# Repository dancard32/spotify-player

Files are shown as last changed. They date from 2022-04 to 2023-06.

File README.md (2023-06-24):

# Raspberry Pi - RFID Spotify Jukebox

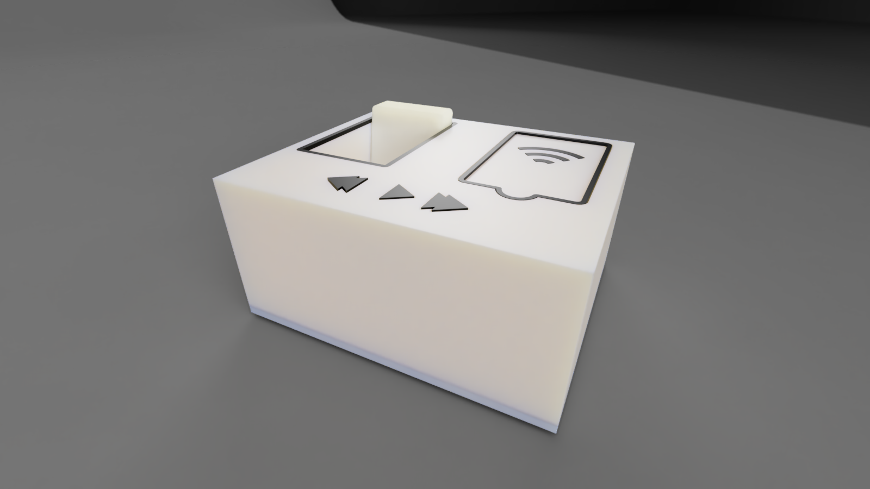
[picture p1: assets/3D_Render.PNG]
Cover Photo

## Description
Ths project employs the [spotipy](https://spotipy.readthedocs.io/en/2.19.0/) Python library to interface with the Spotify web application to create a functional RFID Spotify Jukebox. This Github repository will contain the steps towards creating a functional spotify application as well as containing links to the thingiverse repository of the *.stl* files that I 3D printed as well as the Bill of Materials (BOM).

---
## Table of Contents
- [Bill of Materials](#bill-of-materials)
    - [Raspberry Pi](#raspberry-pi)
    - [RFID Card Reader](#rfid-card-reader)
    - [Miscellaneous Parts](#miscellaneous-parts)
- [Installation and Setup](#installation-and-setup)
    - [Initial Set-up](#initial-set-up)
    - [RC522 Card Reading](#rc522-card-reading)
    - [Connecting Raspberry Pi to Spotify](#connecting-raspberry-pi-to-spotify)
    - [Setting up Developer Spotify API](#setting-up-developer-spotify-api)
    - [Installing Spotipy](#installing-spotipy)
    - [Adding Playlists/Songs to RFID Cards](#adding-playlistssongs-to-rfid-cards)
    - [Enabling Spotipy Script on Boot](#enabling-spotipy-script-on-boot)
- [Printing Album Art](#printing-album-art)
- [3D Printing Jukebox](#3d-printing-jukebox)
- [Credits](#credits)
- [License](#license)

---
## Bill of Materials
Listed below are the bare minimum parts required for a functioning Raspberry Pi RFID Spotify jukebox, with associated links:
- ### Raspberry Pi
    There are several Raspberry Pi's that can be used, but ultimately depend on the implementation
    - [Raspberry Pi 4 Model B](https://www.raspberrypi.com/products/raspberry-pi-4-model-b/)
    - [Raspberry Pi 3 Model B+](https://www.raspberrypi.com/products/raspberry-pi-3-model-b-plus/)
    - [Raspberry Pi 3 Model B](https://www.raspberrypi.com/products/raspberry-pi-3-model-b/)

- ### RFID Card Reader
    It is best to use a [RC522 RFID](https://medium.com/autonomous-robotics/an-introduction-to-rfid-dc6228767691) due to its supported Python library module. You can pick one up [here](https://www.amazon.com/dp/B07VLDSYRW?psc=1&ref=ppx_yo2ov_dt_b_product_details).

- ### Miscellaneous Parts
    - **Speaker**: in this build I used a [JBL Flip 3](https://www.amazon.com/JBL-FLIP3-Bluetooth-Speaker-Black/dp/B010RWAIAC) that I purchased on a Black Friday Deal for $30, any speaker will suffice - edits to the 3D prints will be needed with a different speaker configuration
    - **Button**: to skip tracks, play/pause tracks I used [Tactile Push Button Switch](https://www.amazon.com/QTEATAK-Momentary-Tactile-Button-Switch/dp/B07VSNN9S2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) or a suitable alternative
    - **Audio Jack Splitter**: To allow external speaker player I got this audio jack that will mount into the 3D printed frame [Audio Jack Splitter](https://www.amazon.com/Kingtop-Adapter-Tablet-Headsets-Version/dp/B01I3A47I4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)
    - **RFID Tags**: Link [here](https://www.amazon.com/dp/B01LZYOR7P?psc=1&ref=ppx_yo2ov_dt_b_product_details)
    - **Blank Cards**: Link [here](https://www.amazon.com/dp/B07193KG7G?ref=ppx_yo2ov_dt_b_product_details&th=1)
    - **Threaded inserts**: Link [here](https://www.amazon.com/dp/B08Z86Z85R?psc=1&ref=ppx_yo2ov_dt_b_product_details)
    - **Dupont Connectors**: Link [here](https://www.amazon.com/dp/B089FZ79CS?psc=1&ref=ppx_yo2ov_dt_b_product_details)
    - **Protoboard**: Link [here](https://www.amazon.com/dp/B07FFDFLZ3?psc=1&ref=ppx_yo2ov_dt_b_product_details)
    - **Rubber Standoffs**: Link [here](https://www.amazon.com/dp/B08C373VBW?psc=1&ref=ppx_yo2ov_dt_b_product_details)
    - **Raspberry Pi PS Cable**: Link [here](https://www.amazon.com/dp/B01N336XEU?psc=1&ref=ppx_yo2ov_dt_b_product_details)

---
## Installation and Setup

### Initial Set-up
After a clean install of Raspberry Pi Dameon Linux
```
sudo apt-get update
sudo apt-get upgrade
```
Next type the following
```
sudo raspi-config
```
Raspi-config will open a window, from here select "Interfacing Options" and select "SPI" and enable "SPI"
```
sudo reboot
```

### RC522 Card Reading
To allow the reading of RFID tags, connect the MFRC522 module to the Raspberry Pi via the following pin out schematic
- **SS pin** connects to **GPIO8 pin**
- **SCK pin** connects to **GPIO11 pin**
- **MOSI pin** connects to **GPIO10 pin**
- **MISO pin** connects to **GPIO9 pin**
- **IRQ pin** does not connect to anything
- **GND pin** connects to **GND pin**
- **RST pin** connects to **GPIO23 pin**
- **VCC pin** connects to **3.3V Power pin**

Refer to the pins and connections below
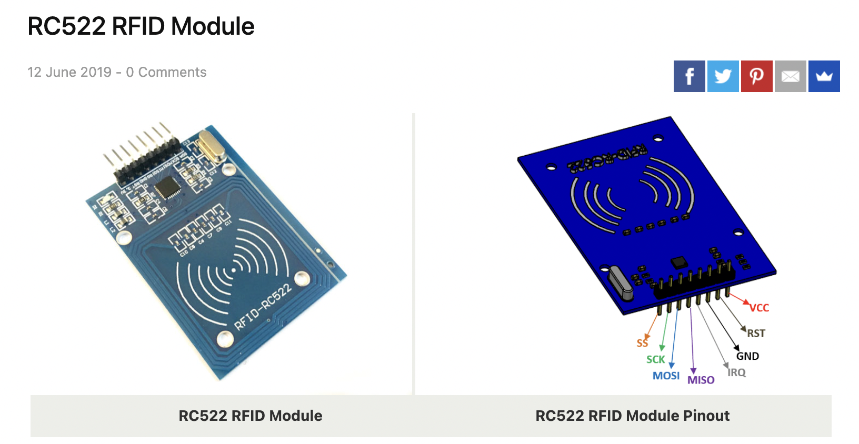
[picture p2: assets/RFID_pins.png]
MFRC522 RFID Card Reader Pin Out

Click here for more [RC522 Data](https://components101.com/wireless/rc522-rfid-module)

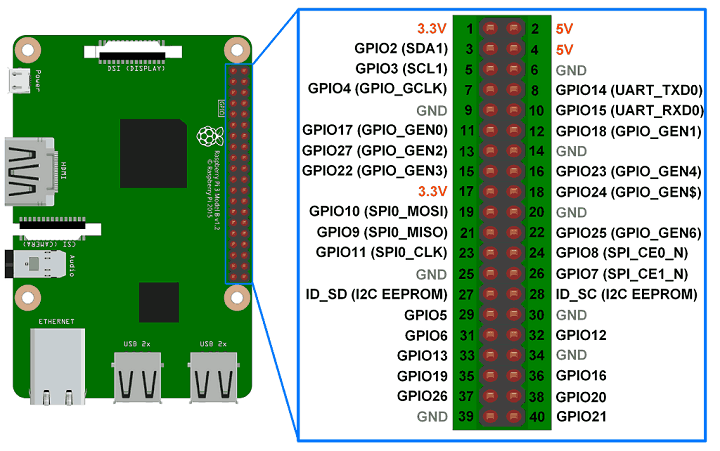
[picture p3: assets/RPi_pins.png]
Raspberry Pi 3/4 GPIO Pin Outs


To allow for the RFID reading, install the following dependencies
```
sudo apt-get install python3-dev python3-pip
sudo pip3 install spidev mfrc522
```
This will enable the Raspberry Pi to access the GPIO pins and read the HASH ID values from the RFID tags that can be used to link to playlists/albums/tracks later on. With these dependencies installed *readCard.py* should be able to run and will output the HASD ID values.

### Connecting Raspberry Pi to Spotify
To enable the Raspberry Pi to be a valid connection on Spotify, the [Raspotify - Spotify Connect](https://github.com/dtcooper/raspotify) client will need to be installed - *be sure that all dependencies are met else connect will not work*- to install use the folllowing command
```
sudo apt-get -y install curl && curl -sL https://dtcooper.github.io/raspotify/install.sh | sh
```
While the Raspberry Pi is on and connected to internet, it should be recognized by Spotify as a valid connection device (analogous to a bluetooth speaker, a separate device, etc). Test functionality by opening Spotify on a phone or laptop and click the **Connect** button and search for "Raspotify" in the options.
### Setting up Developer Spotify API
Next step is too allow the Raspberry Pi to interface with Spotify's web API and allow the Raspberry Pi to change music per the RFID values. To allow *spotipy* to integrate with the Spotify web API, API tokens are required, to obtain them do the following:

1. Navigate to https://developer.spotify.com/dashboard
2. Sign in with a Spotify Premium Account
3. Click "Create an App"
4. Click on your app
5. Click on "Edit Settings"
6. Add the following callback URIs
```
http://localhost:8888/callback
http://localhost:8080 
```
7. On the dashboard, write/copy the Client ID and Client Secret, they are needed later

Next is to get the Device ID of the Raspberry Pi, this can be found after connecting the Raspberry Pi via Spotify Connect

1. On a phone or laptop, open Spotify and connect to "Raspotify"
2. Navigate to https://developer.spotify.com/console/get-users-available-devices/
3. Click get token
4. Check all the boxes under "Required Scopes for this endpoint"
5. Click "Request Token"
6. Underneath the Get token option, click "Try It" to make an API call and get the list of Spotify devices on your home network
7. In the json response, find the ID for the Raspotify (Raspberry Pi) device
8. Write/copy the Device ID

### Installing Spotipy
Spotipy is a lightweight python library for the Spotify web API, click here for [Spotipy Documentation](https://spotipy.readthedocs.io/en/2.19.0/)
```
pip install spotipy
```
Once that installs, we can start writing our first python program to control Spotify on Raspberry Pi.

1. In your main folder, open *parseSpotify.py*
2. Change the Device ID, Client ID, and Client Secret to the tokens provided by Spotify
3. Execute this script
4. A Spotify webpage will open where you have to agree/accept to authenticate. Click agree, this is a one-time setup
5. Once authenticated, the song in *parseSpotify.py* will start playing through the Raspberry Pi speakers

### Adding Playlists/Songs to RFID Cards
With everything up to this point being completed, the Raspberry Pi is ready to play music! Change the token values in *main.py* to match the tokens provided to you from Spotify. From here songs/albums/playlists can be added to the *CardData.json* through the following format shown below:
```
{
    "HASH ID #1 FROM RFID CARD":{
        "name":"Road Trips",
        "url":"spotify:playlist:1LxEqGRyNV5yB67e6mwGgH",
    },
    "HASH ID #2 FROM RFID CARD":{
        "name":"California 37",
        "url":"spotify:album:5zseibu9WEsPaZmkJUMkz1",
    },
    "HASH ID #3 FROM RFID CARD":{
        "name":"Beautiful Mistakes",
        "url":"spotify:track:5zFglKYiknIxks8geR8rcL",
    },
}
```
Where *HASH ID* can be found by running the *readCard.py* script and copying/pasting the RFID HASH ID into *CardData.json* and where *"type"* can be either *Playlist, Album, or Track* as per the Spotify URL. Obtaining the URL can be done simply by:
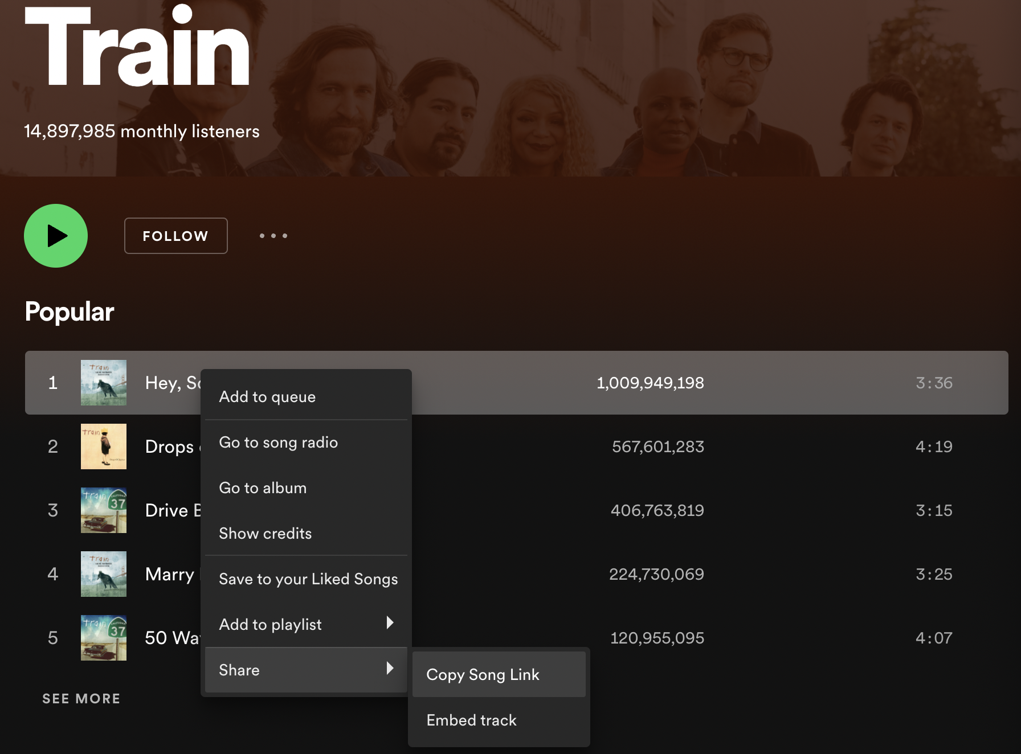
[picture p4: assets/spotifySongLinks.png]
Spotify Song Links


Copying this link gives *https://open.spotify.com/track/4HlFJV71xXKIGcU3kRyttv?si=b945f2f735874dd0* but all that is is needed can be spliced is after the *spotify.com/"type"/* up to the *"?"* such that this track's ID is **4HlFJV71xXKIGcU3kRyttv**. Hence, the value for the card's URL is
```
{
    "name":"Hey, Soul Sister",
    "url":"spotify:track:4HlFJV71xXKIGcU3kRyttv",
    "type": "Track"
}
```
**Note: The type must be correct as album/playlist use a different API call than track, the name can be left blank**

### Enabling Spotipy Script on Boot
Enabling the python script to auto-run on boot can be done by using *crontab* to run a shell script that starts the script on boot. For detailed instructions, refer to [Raspberry Pi Launch Python Script on Startup](https://www.instructables.com/Raspberry-Pi-Launch-Python-script-on-startup/)

---
## Printing Album Art
Included in this repository is the *genPhotos.py* file that will automatically generate the album art to be printed, cut out and pasted onto a blank card to pose as a modern record. All that is required is enabling the *boolean* to automatically pull the album art from Spotify - else you'll have to manually populate the album cover art folder with photos of your choice.

### Custom Art
To print custom artworks (not the album art from Spotify), place your artwork into the *cover_art* folder shown below with the associated name that can be found in the *CardData.json*

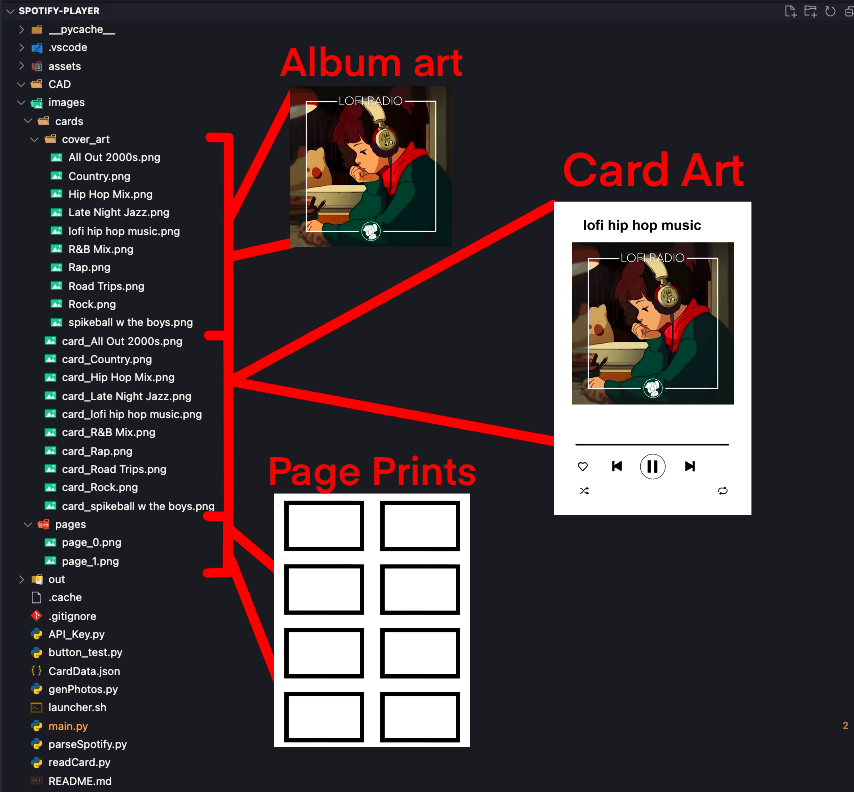
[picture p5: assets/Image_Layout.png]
Image Layout


**Ensure that PullSpotifyData is False if you want custom album art**

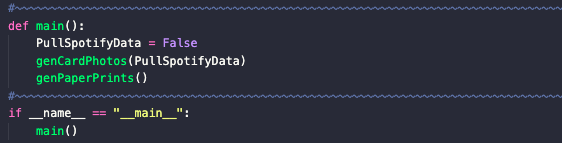
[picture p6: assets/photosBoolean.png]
genPhotos.py Boolean


*genPhotos.py*
## 3D Printing Jukebox
All the 3D printing CAD files can be found under the associated *CAD* folder in this repository. These are in the *.stl* file format to be used during *.gcode* generation. Additionally, the drawing with the bill of materials (BOM) can be found in this folder as well.

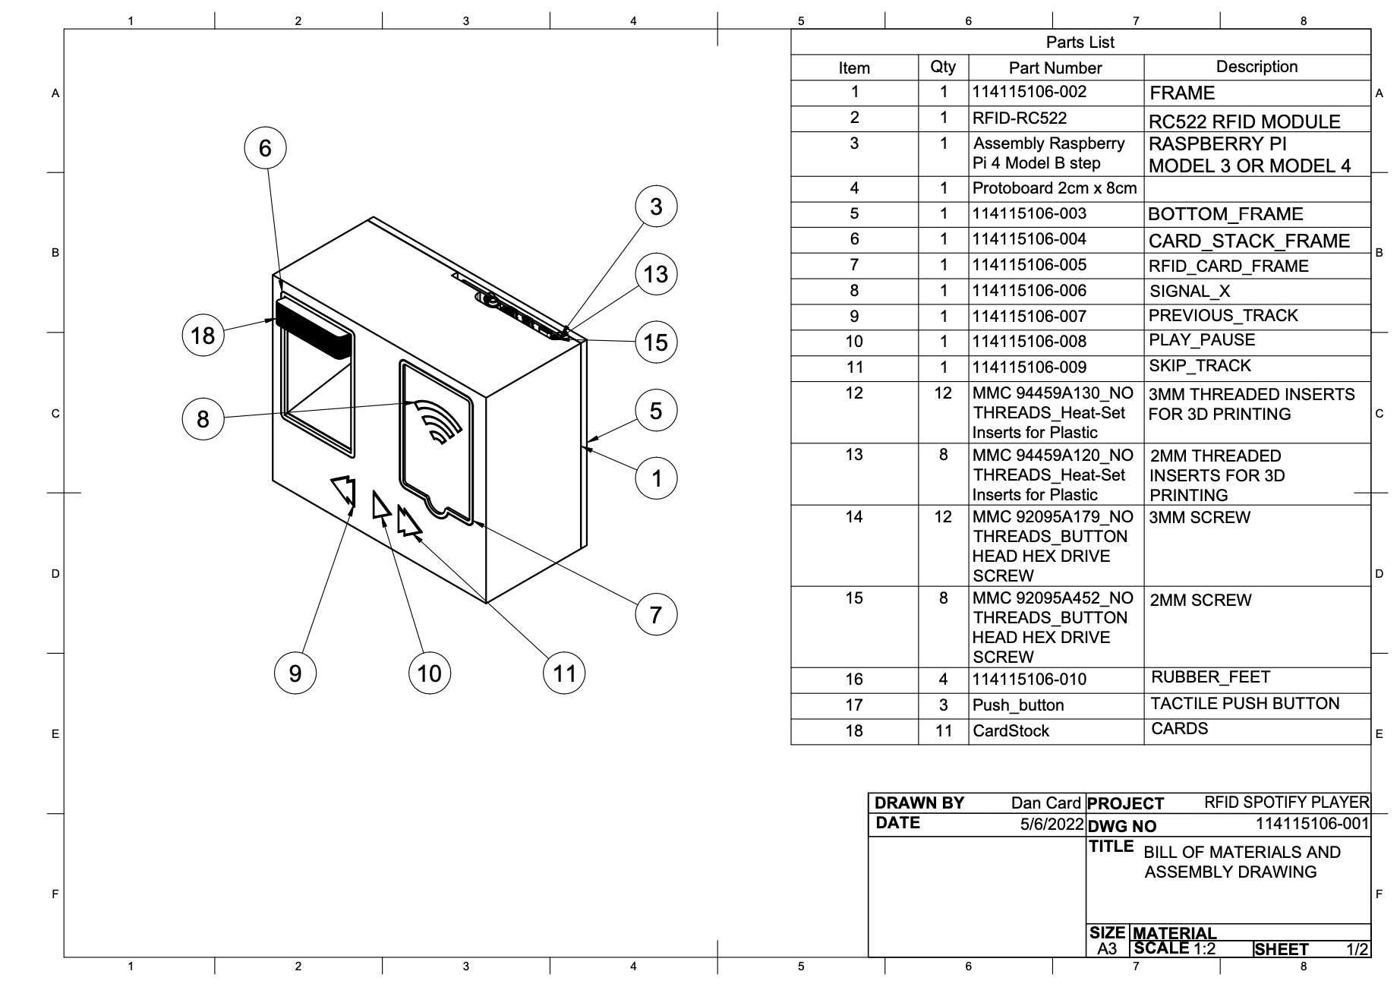
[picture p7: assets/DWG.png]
Bill of Materials


The parts that end in an *-0XX* are those that are printed and not bought locally (exception of the rubber feet if preferred). Additionally, to enable the previous/play & pause/skip track buttons electrically wiring the buttons with soulder will be required. The electrical configuration is as follows.

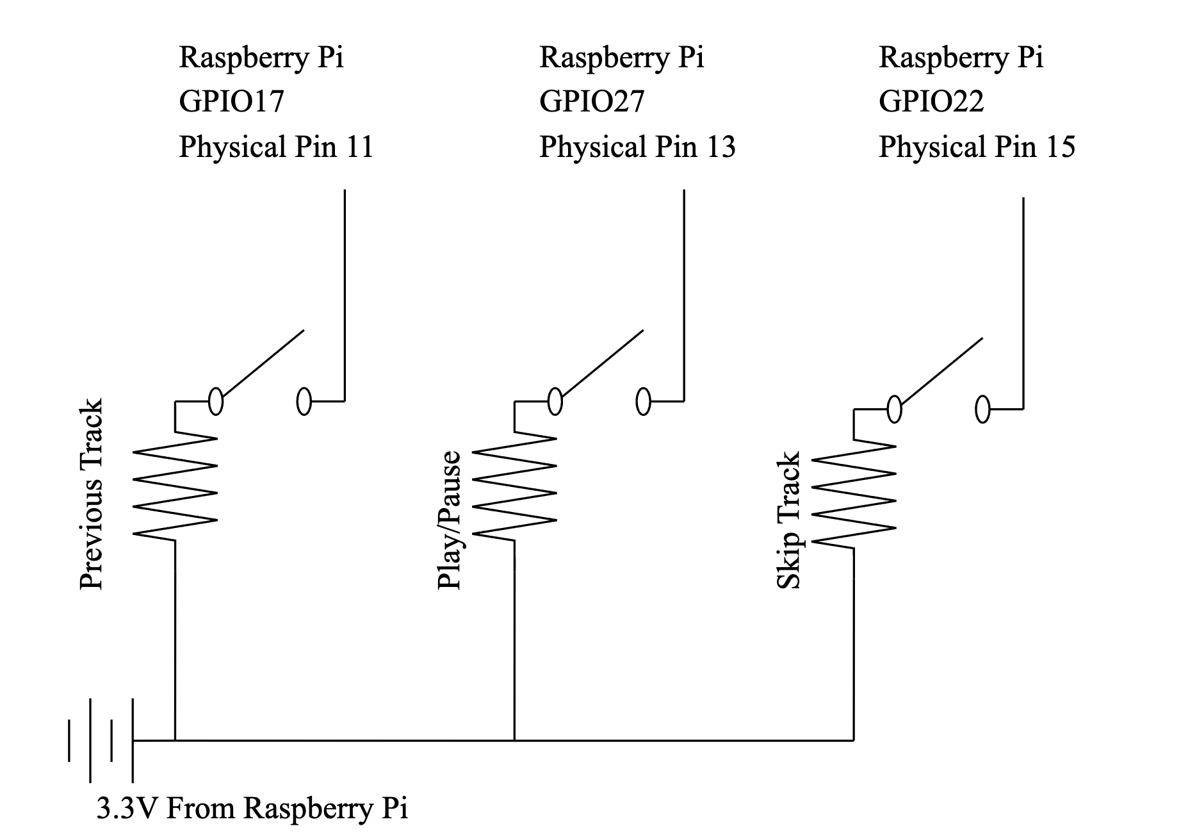
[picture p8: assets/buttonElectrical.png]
Button Electrical Configuration

---
## Credits
This repository and project is based upon the work of [talaexe's Sptoify-RFID-Record-Player](https://github.com/talaexe/Spotify-RFID-Record-Player) and expanded upon to allow more features and scalability. Additionally, this work extensively uses [Spotipy](https://spotipy.readthedocs.io/en/2.19.0/) of which is the Python library that allows Web API calls to Spotify. Finally, this also extensively uses the [Raspotify](https://github.com/dtcooper/raspotify) library to integrate with Raspberry Pi and Spotify to allow music playing.

## License
Attribution-NonCommercial-ShareAlike 4.0 International (CC BY-NC-SA 4.0) prohibits the use of this for commercialization, but allows downloading editing/sharing amongst the community. If there is a request to commercialize, contact me personally via email at [dcard@umich.edu](mailto:dcard@umich.edu)

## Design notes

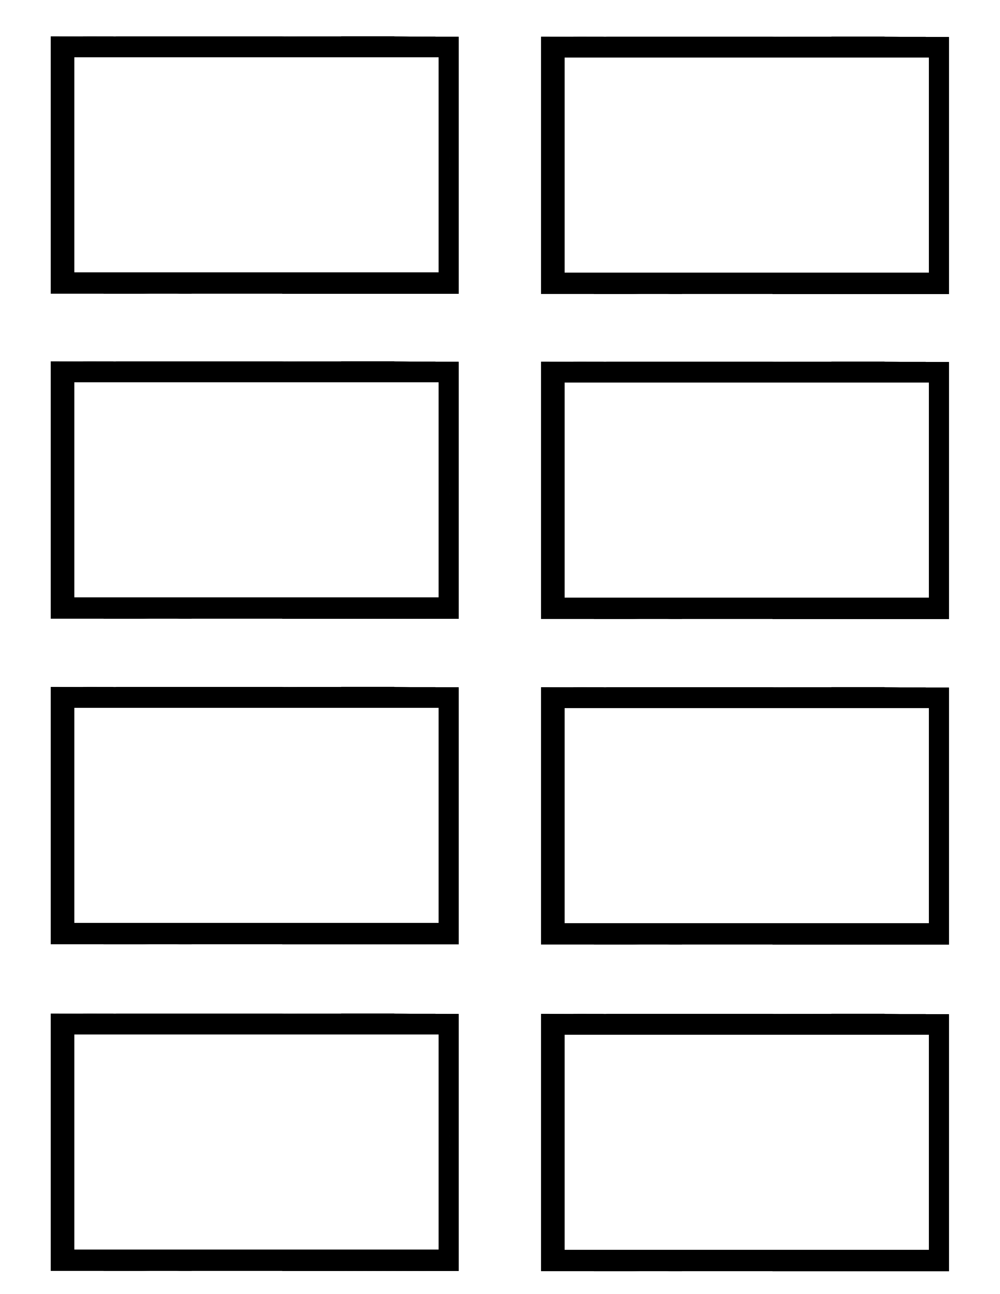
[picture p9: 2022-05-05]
assets/Paper_Template.png

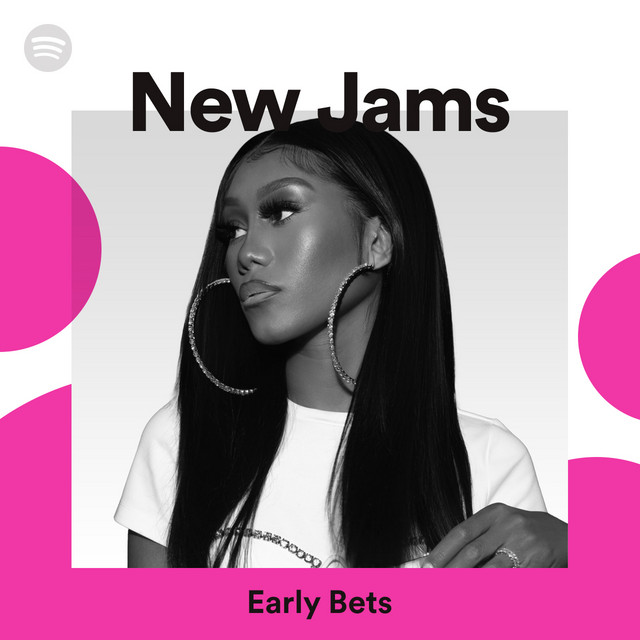
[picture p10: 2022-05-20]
images/cards/cover_art/New Jams.png

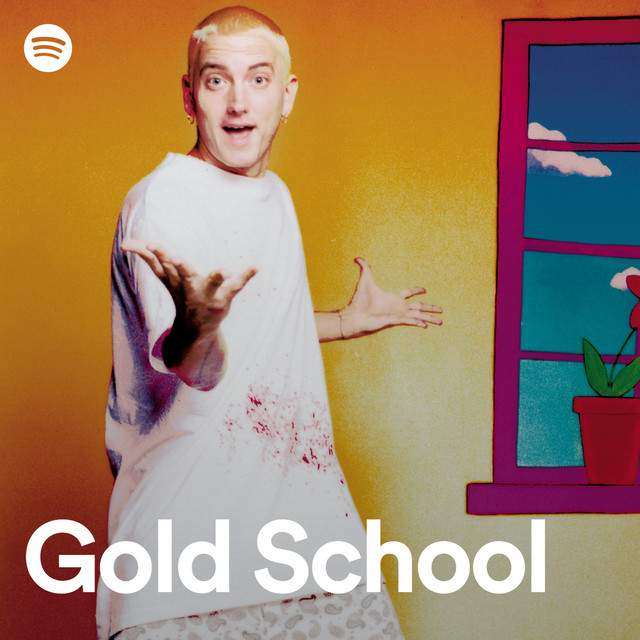
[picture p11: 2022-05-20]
images/cards/cover_art/Gold School.png

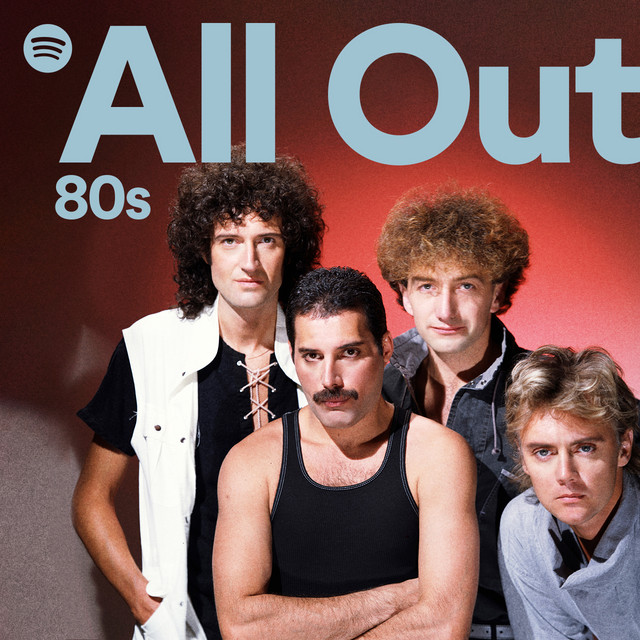
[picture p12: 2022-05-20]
images/cards/cover_art/All Out 80s.png

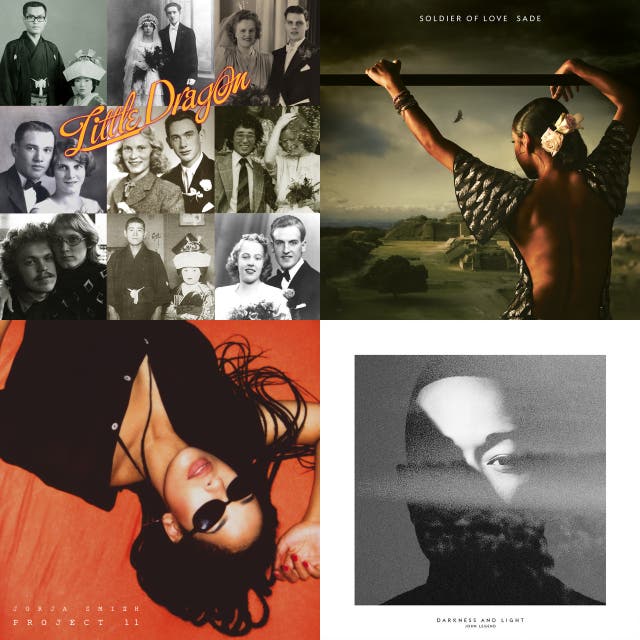
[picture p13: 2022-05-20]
images/cards/cover_art/Jonni's Mix.png

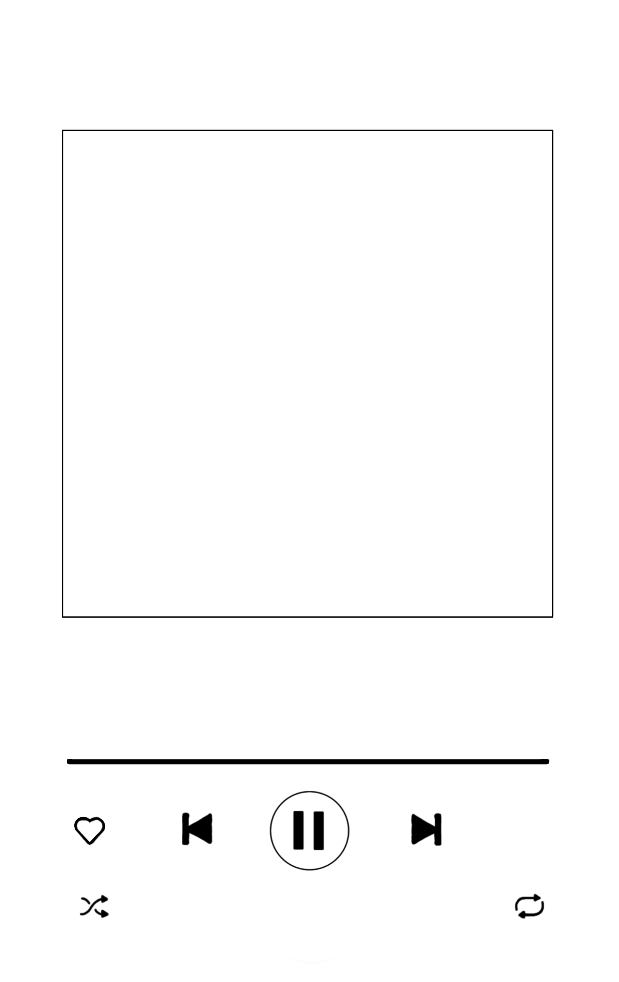
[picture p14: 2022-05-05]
assets/Blank_Card.png

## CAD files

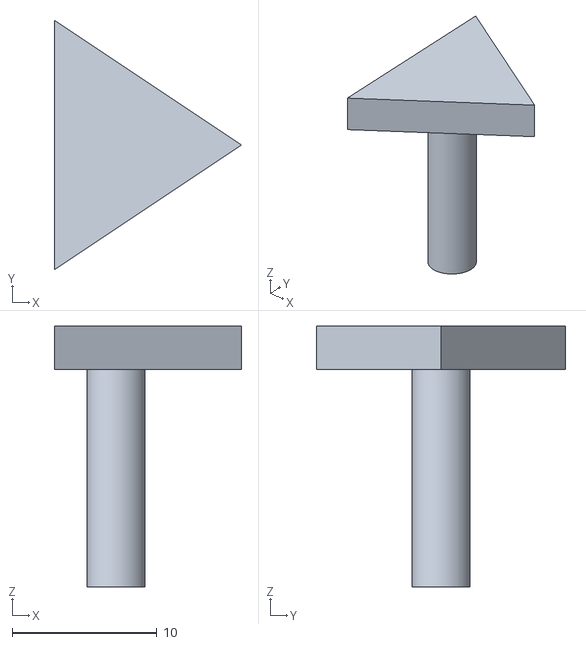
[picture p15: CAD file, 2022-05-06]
CAD/PLAY_PAUSE.stl
12.9 x 17.2 x 18.0

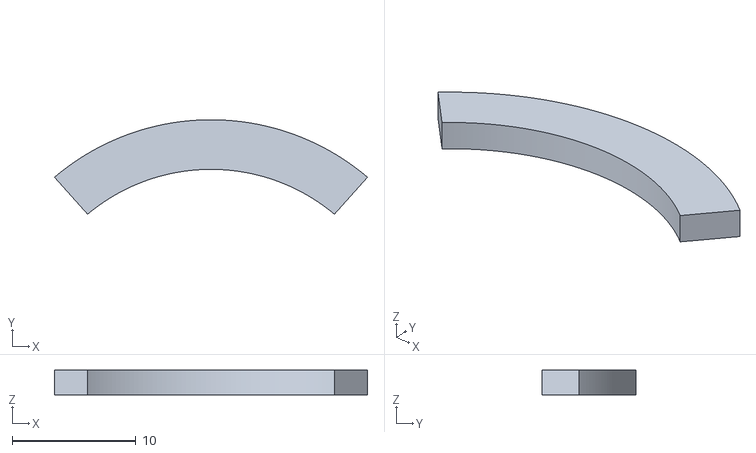
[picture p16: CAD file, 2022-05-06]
CAD/SIGNAL_2.stl
25.2 x 7.62 x 2.00

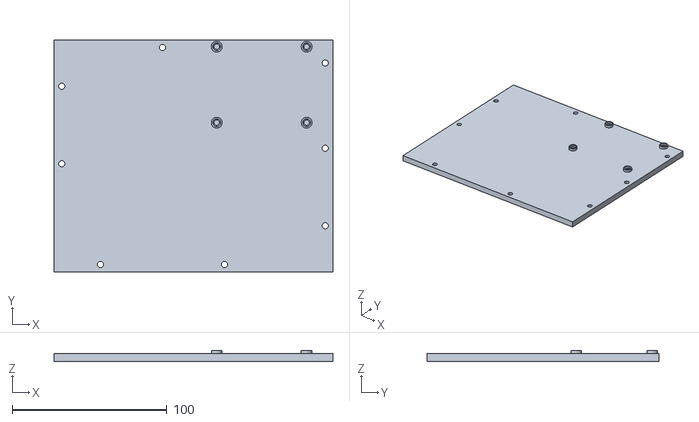
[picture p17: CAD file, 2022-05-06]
CAD/BOTTOM_FRAME.stl
180.0 x 150.0 x 7.00

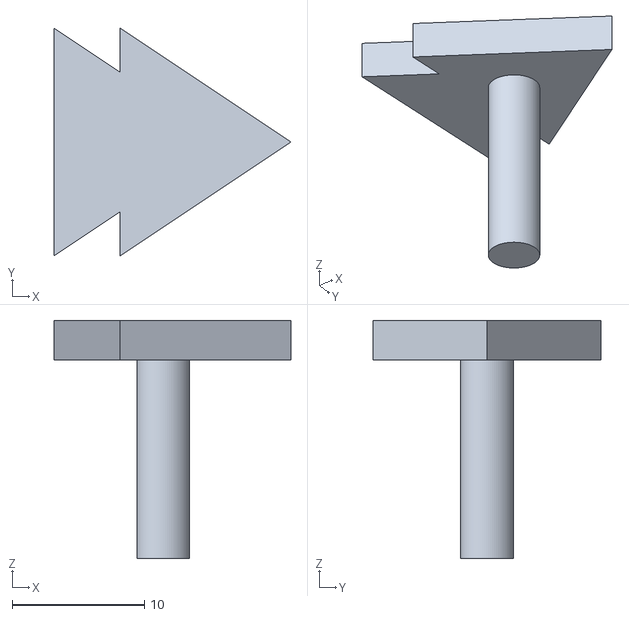
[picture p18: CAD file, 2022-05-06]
CAD/SKIP_TRACK.stl
17.9 x 17.2 x 18.0

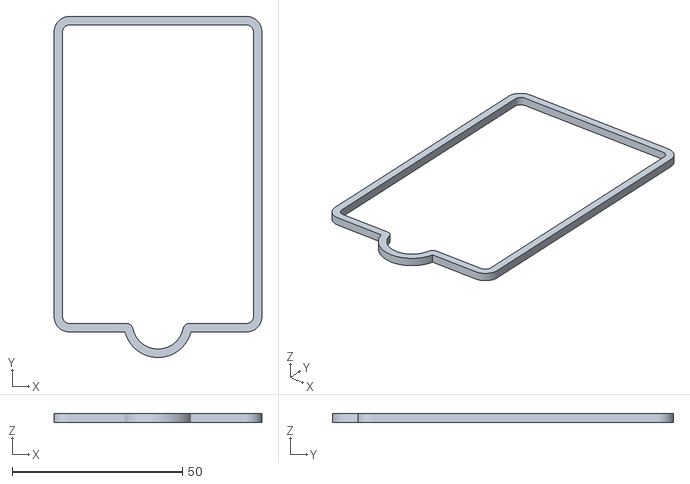
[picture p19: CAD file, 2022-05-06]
CAD/RFID_CARD_FRAME.stl
61.0 x 100.1 x 2.50

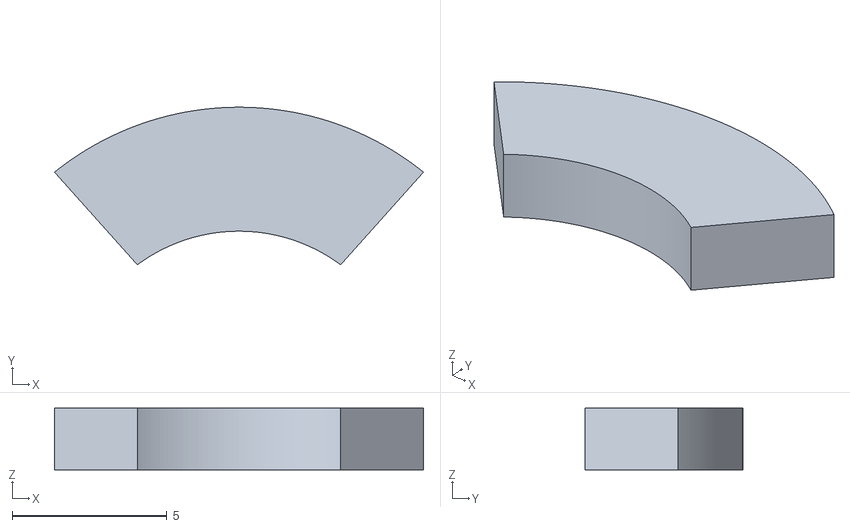
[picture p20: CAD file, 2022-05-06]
CAD/SIGNAL_1.stl
11.9 x 5.08 x 2.00

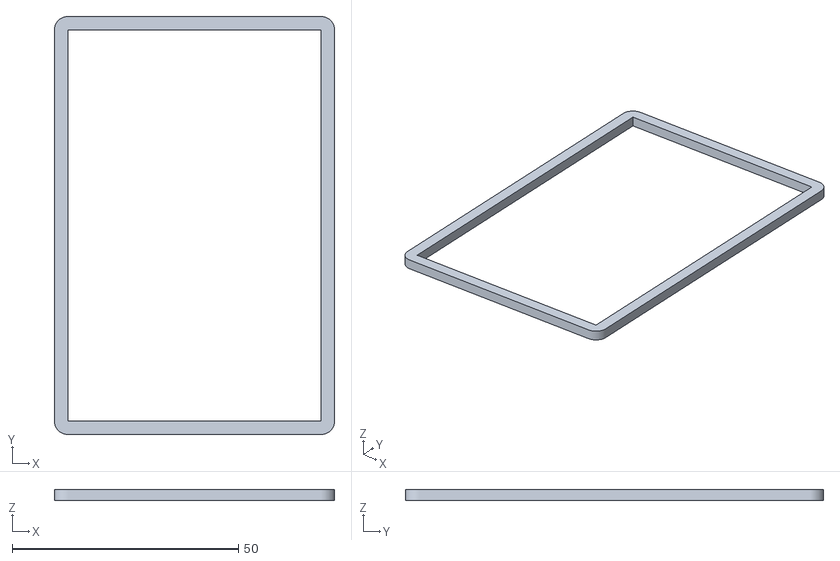
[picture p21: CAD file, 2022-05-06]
CAD/CARD_STACK_FRAME.stl
62.0 x 92.4 x 2.50

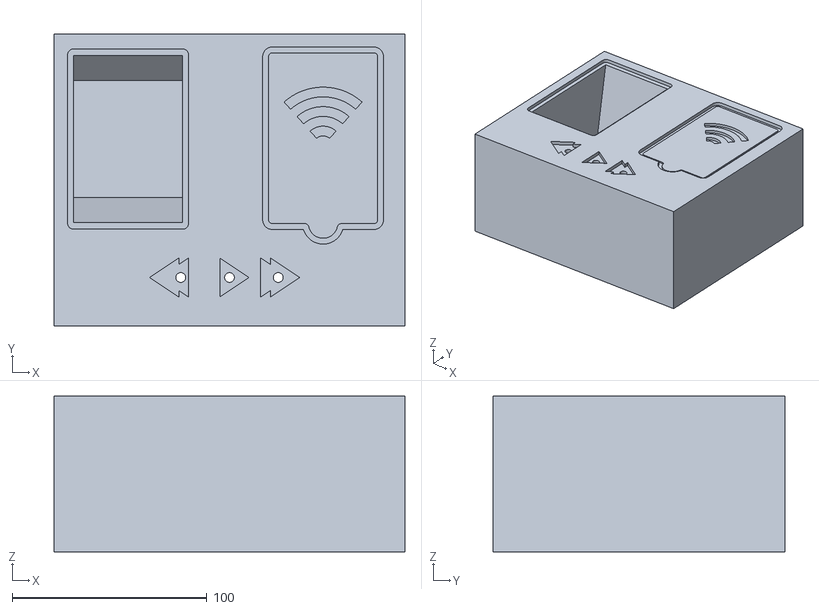
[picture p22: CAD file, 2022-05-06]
CAD/FRAME.stl
180.0 x 150.0 x 80.0

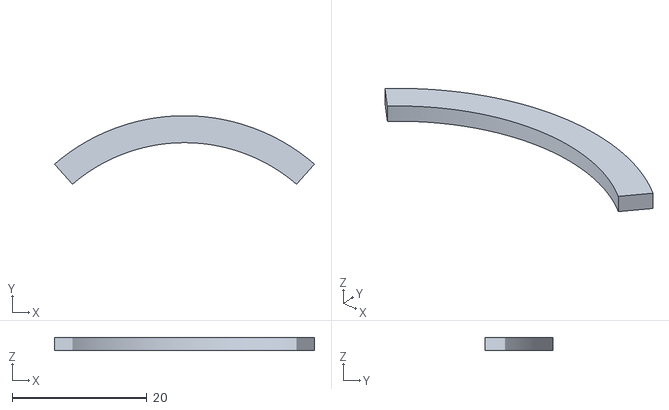
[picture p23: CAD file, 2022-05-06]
CAD/SIGNAL_3.stl
38.6 x 10.2 x 2.00

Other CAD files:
CAD/PREVIOUS_TRACK.stl

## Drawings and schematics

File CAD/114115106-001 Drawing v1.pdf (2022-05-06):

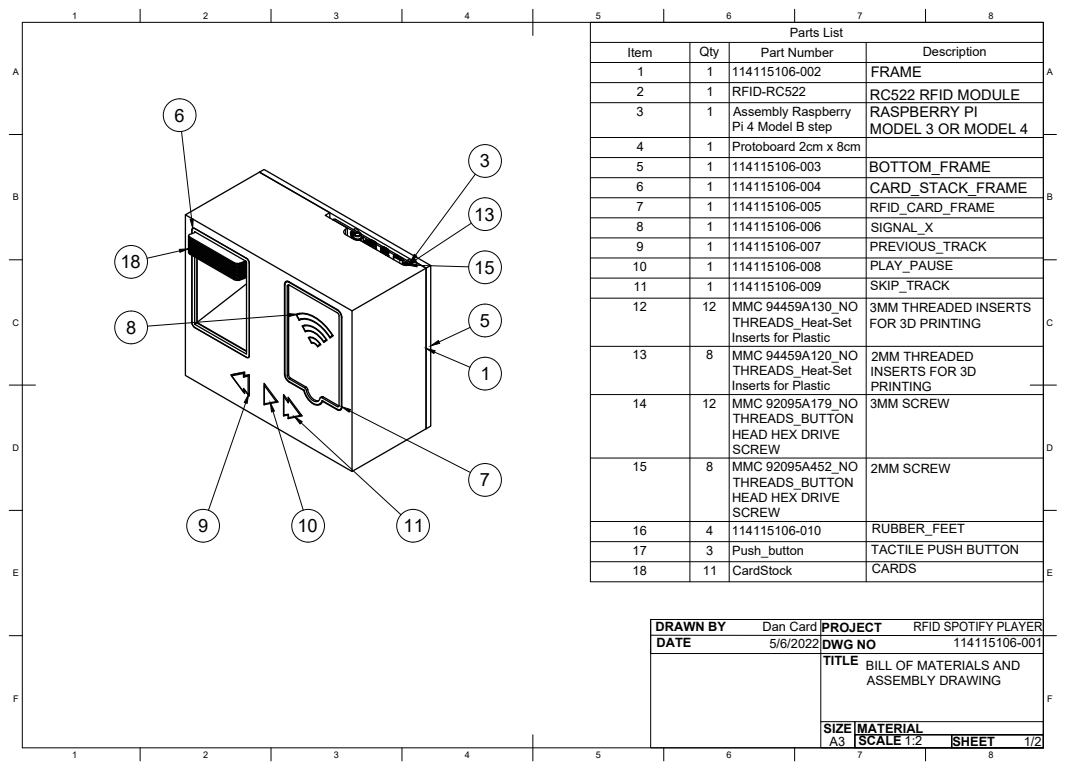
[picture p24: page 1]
8 BCDEF; ABCDEF; Parts List

Item | Qty 1 1 1 | 114115106-002 2 RFID-RC522 3 Assembly Raspberry Part Number | Description 1 FRAME

RC522 RFID MODULE
RASPBERRY PI MODEL 3 OR MODEL 4

1 1 1 | 114115106-003 6 114115106-004 7 114115106-005 8 114115106-006 9 114115106-007 Pi 4 Model B step 4 Protoboard 2cm x 8cm 5 | BOTTOM_FRAME

CARD_STACK_FRAME
RFID_CARD_FRAME
SIGNAL_X
PREVIOUS_TRACK

10 | 1 | 114115106-008 | PLAY_PAUSE
11 | 1 | 114115106-009 | SKIP_TRACK
12 | 12 | MMC 94459A130_NO THREADS_Heat-Set Inserts for Plastic | 3MM THREADED INSERTS FOR 3D PRINTING

18 14 | 11 12 | CardStock 715 MMC 92095A179_NO THREADS_BUTTON HEAD HEX DRIVE SCREW | 3MM SCREW

13 | 8 | MMC 94459A120_NO THREADS_Heat-Set Inserts for Plastic | 2MM THREADED INSERTS FOR 3D PRINTING

15 | 8 | MMC 92095A452_NO THREADS_BUTTON HEAD HEX DRIVE SCREW | 2MM SCREW

16 | 4 | 114115106-010 | RUBBER_FEET
17 | 3 | Push_button | TACTILE PUSH BUTTON

CARDS

DRAWN BY Dan Card DATE 5/6/2022 | PROJECT RFID SPOTIFY PLAYER DWG NO 114115106-001

TITLE BILL OF MATERIALS AND ASSEMBLY DRAWING

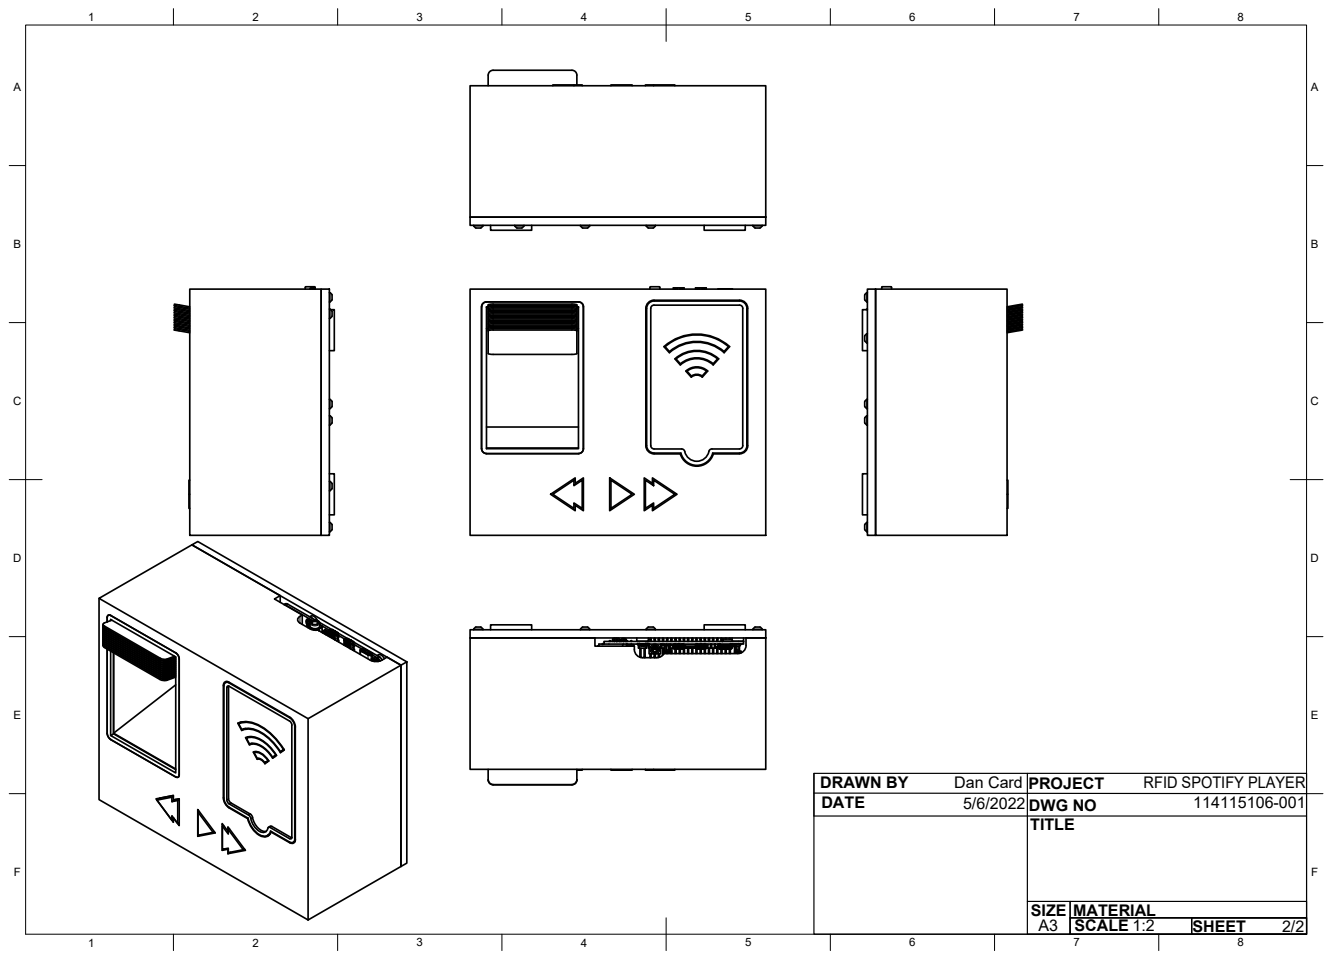
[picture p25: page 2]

DRAWN BY Dan Card DATE 5/6/2022 | PROJECT RFID SPOTIFY PLAYER DWG NO 114115106-001

TITLE

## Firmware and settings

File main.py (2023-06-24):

from mfrc522 import SimpleMFRC522       # Python module to read RFID tags
import RPi.GPIO as GPIO                 # Allows RPi to interface with GPIO
from time import sleep                  # Timeout to wait for web API call
import spotipy                          # Spotipy's python module
from spotipy.oauth2 import SpotifyOAuth # Allows authentication of Spotify
import json                             # Used to input CardData.json
from API_Key import API_KEY             # Allows constants across scripts
#~~~~~~~~~~~~~~~~~~~~~~~~~~~~~~~~~~~~~~~~~~~~~~~~~~~~~~~~~~~~~~~~~~~~~~~~~~~~~~
""" Globally loaded constants """
DEVICE_ID, CLIENT_ID, CLIENT_SECRET = API_KEY()
PLAY_PAUSE = True # True while playing, False while paused

fid = open('CardData.json') # Open the .json data
TrackData = json.load(fid)  # Load the .json
fid.close()                 # Close out
#~~~~~~~~~~~~~~~~~~~~~~~~~~~~~~~~~~~~~~~~~~~~~~~~~~~~~~~~~~~~~~~~~~~~~~~~~~~~~~
def parseRFID(id):
    """
    parseRFID inputs the RFID hash ID and returns the url, associated name, and
    the type of music (either playlist/track/album).

    Attributes:
        id (int): The integer value read in via the GPIO pins of the RPi
    """
    url = TrackData[str(id)]["url"]
    name = TrackData[str(id)]["name"]
    type = url.split(":")[1].lower()

    return url, name, type
#~~~~~~~~~~~~~~~~~~~~~~~~~~~~~~~~~~~~~~~~~~~~~~~~~~~~~~~~~~~~~~~~~~~~~~~~~~~~~~
def printInfo(data):
    """
    printInfo prints to terminal the music data

    Attributes:
        data (dict): The returned data via the Spotify Web API
    """
    print(f"Playing {data['item']['name']} by {data['item']['artists'][0]['name']}")
#~~~~~~~~~~~~~~~~~~~~~~~~~~~~~~~~~~~~~~~~~~~~~~~~~~~~~~~~~~~~~~~~~~~~~~~~~~~~~~
def pausePlayTrack(channel):
    """
    pausePlayTrack GPIO callback function to allow RPi to play or pause music
    through spotify

    Attributes:
        channel (BOARD): Inhereted from GPIO.setmode(GPIO.BOARD)
    """
    global PLAY_PAUSE   # global variable to allow several function callbacks

    print("Play/Pause")
    if PLAY_PAUSE:
        sp.pause_playback(device_id=None)
        PLAY_PAUSE = False
    else:
        sp.start_playback(device_id=None)
        PLAY_PAUSE = True
        info = sp.currently_playing()
        printInfo(info)
#~~~~~~~~~~~~~~~~~~~~~~~~~~~~~~~~~~~~~~~~~~~~~~~~~~~~~~~~~~~~~~~~~~~~~~~~~~~~~~
def skipTrack(channel):
    """
    skipTrack GPIO callback function to allow RPi to skip current track

    Attributes:
        channel (BOARD): Inhereted from GPIO.setmode(GPIO.BOARD)
    """

    print("Skip track")
    sp.next_track(device_id=None)
    info = sp.currently_playing()
    printInfo(info)
#~~~~~~~~~~~~~~~~~~~~~~~~~~~~~~~~~~~~~~~~~~~~~~~~~~~~~~~~~~~~~~~~~~~~~~~~~~~~~~
def backTrack(channel):
    """
    backTrack GPIO callback function to allow RPi to go to previous track

    Attributes:
        channel (BOARD): Inhereted from GPIO.setmode(GPIO.BOARD)
    """

    print("Previous track")
    sp.previous_track(device_id=None)
    info = sp.currently_playing()
    printInfo(info)
#~~~~~~~~~~~~~~~~~~~~~~~~~~~~~~~~~~~~~~~~~~~~~~~~~~~~~~~~~~~~~~~~~~~~~~~~~~~~~~
""" RPi set-up to allow button pushing """
GPIO.setwarnings(False)
GPIO.setmode(GPIO.BOARD)

# GPIO setup on PIN 11 to play/pause music
GPIO.setup(11, GPIO.IN, pull_up_down=GPIO.PUD_DOWN)
GPIO.add_event_detect(11, GPIO.RISING, callback=pausePlayTrack)

# GPIO setup on PIN 13 to skip the current track
GPIO.setup(13, GPIO.IN, pull_up_down=GPIO.PUD_DOWN)
GPIO.add_event_detect(13 , GPIO.RISING, callback=skipTrack)

# GPIO setup on PIN 15 to play the previous track
GPIO.setup(15, GPIO.IN, pull_up_down=GPIO.PUD_DOWN)
GPIO.add_event_detect(15, GPIO.RISING, callback=backTrack)
#~~~~~~~~~~~~~~~~~~~~~~~~~~~~~~~~~~~~~~~~~~~~~~~~~~~~~~~~~~~~~~~~~~~~~~~~~~~~~~
""" Main loop on start up """
while True:
    try:
        reader = SimpleMFRC522()
        sp = spotipy.Spotify(auth_manager=SpotifyOAuth(client_id=CLIENT_ID,
                client_secret=CLIENT_SECRET,
                redirect_uri="http://localhost:8080",
                scope="user-read-playback-state,user-modify-playback-state"))

        # Loop to read in RFID Card's
        while True:
            print("\nWaiting for record scan...")

            id = reader.read()[0]
            print(f"Card Value is: {id}")
            sp.transfer_playback(device_id=None, force_play=False)

            # Once the RFID card is read, parse the data for music selection
            if id: url, name, type = parseRFID(id)

            # If track type is selected play the track
            if type == "track":
                print(f"Playing {type}: {name}")
                sp.start_playback(device_id=None, uris=[url])
                sleep(1)
                info = sp.currently_playing()
                printInfo(info)

            # With Playlist/Album type use context_uri and enable shuffle
            elif type == "playlist" or type == "album":
                print(f"Playing {type}: {name}")
                sp.start_playback(device_id=None, context_uri=url)
                sp.shuffle(True, device_id=None)
                sp.next_track()
                sleep(1)
                info = sp.currently_playing()
                printInfo(info)

    # Print the error and continue the loop
    except Exception as e:
        print(e)
        pass

    # Cleanup the GPIO input for the next RFID card to be read
    finally:
        print("Cleaning up GPIO...")
        GPIO.cleanup()
#~~~~~~~~~~~~~~~~~~~~~~~~~~~~~~~~~~~~~~~~~~~~~~~~~~~~~~~~~~~~~~~~~~~~~~~~~~~~~~

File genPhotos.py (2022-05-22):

from PIL import Image, ImageDraw, ImageFont # PIL library to modify images
import urllib.request                   # Python library to save images
import spotipy                          # Spotipy's python module
from spotipy.oauth2 import SpotifyOAuth # Allows authentication of Spotify
import json                             # Used to input CardData.json
from API_Key import API_KEY             # Allows constants across scripts
import random                           # Used for track circle placement
import numpy as np                      # Used to floor song duration played
import os                               # Used to delete cards
#~~~~~~~~~~~~~~~~~~~~~~~~~~~~~~~~~~~~~~~~~~~~~~~~~~~~~~~~~~~~~~~~~~~~~~~~~~~~~~
""" Globally loaded constants """
DEVICE_ID, CLIENT_ID, CLIENT_SECRET = API_KEY()

fid = open('CardData.json') # Open the .json data
TrackData = json.load(fid)  # Load the .json
fid.close()                 # Close out

# Authenticate spotipy to pull images
sp = spotipy.Spotify(auth_manager=SpotifyOAuth(client_id=CLIENT_ID,
                client_secret=CLIENT_SECRET,
                redirect_uri="http://localhost:8080",
                scope="user-read-playback-state,user-modify-playback-state"))
#~~~~~~~~~~~~~~~~~~~~~~~~~~~~~~~~~~~~~~~~~~~~~~~~~~~~~~~~~~~~~~~~~~~~~~~~~~~~~~
def genCardPhotos(PullSpotify):
    """
    genCardPhotos generates the Card stacks that will be printed and placed on
    top of the RFID cards. This function can either use custom photos or scrape
    images from Spotify if desired.

    Attributes:
        PullSpotify (bool): True if want default Spotify images

    Notes:
        Custom images must be cropped to a square ratio and saved with the name
        "CardData.json UNIQUE NAME.png" and located in "images/cards/cover_art"
    """

    blank_background = Image.open("assets/Blank_Card.png") # Template card

    # Loop through all songs/playlists/albums in CardData.json
    for names in TrackData.values():
        background = blank_background.copy()
        tmp = names["name"]
         
        # If using Spotify default images
        if PullSpotify:
            # Determine the url for each type of music
            if names["url"].split(":")[1].lower() == "playlist":
                results = sp.playlist_cover_image(names["url"])
                url = results[0]["url"]

            elif names["url"].split(":")[1].lower() == "album":
                results = sp.album(names["url"])
                url = results["images"][0]["url"]

            elif names["url"].split(":")[1].lower() == "track":
                results = sp.track(names["url"])
                url = results["album"]["images"][0]["url"]

            # Save the photo locally
            urllib.request.urlretrieve(url, f"images/cards/cover_art/{tmp}.png")
        img = Image.open(f"images/cards/cover_art/{tmp}.png").resize((1500,1500))

        background.paste(img, (165, 375))

        # Add Card's name to the image
        draw = ImageDraw.Draw(background)
        myFont = ImageFont.truetype("Arial Bold.ttf", 128)
        w, h = draw.textsize(tmp, font=myFont)
        draw.text(((1826-w)/2, 0.05*2896), tmp, fill="black", font=myFont)

        # Add random duration slider
        xloc = random.randint(190, 1620)
        draw.rounded_rectangle((190, 2244, xloc, 2244), fill="yellow", outline="black",
                           width=15, radius=3)
        draw.ellipse((xloc-50, 2244-50, xloc+50, 2244+50), fill="black", outline="black")

        # Add random length of song to card
        songFont = ImageFont.truetype("Arial Bold.ttf", 64)
        song_dur = random.randint(70, 360)
        song_played = (xloc-190)/(1620-190) * song_dur
        draw.text((200, 2120), f"{song_played/60:1.0f}:{song_played%60:02.0f}", fill="black", font=songFont)
        draw.text((1500, 2120), f"{song_dur/60:1.0f}:{song_dur%60:02.0f}", fill="black", font=songFont)

        # Downsize to fit paper_template and save
        background = background.resize((913, 1448))
        background.save(f"images/cards/card_{tmp}.png")
#~~~~~~~~~~~~~~~~~~~~~~~~~~~~~~~~~~~~~~~~~~~~~~~~~~~~~~~~~~~~~~~~~~~~~~~~~~~~~~
def genPaperPrints():
    """
    genPaperPrints uses the custom card stack images and overlays them onto a
    page with sized cutouts to paste onto the RFID cards.
    """

    # Load blank template
    blank_background = Image.open("assets/Paper_Template.png")
    background = blank_background.copy()

    # Initialize enumerators
    i = 0; j = 0; k = 0
    for names in TrackData.values():
        # Obtain the name of the playlist/album/track and open associated image
        tmp = names["name"]
        img = Image.open(f"images/cards/card_{tmp}.png").rotate(90, expand=True)
        
        # Reset counter
        if i == 2: i = 0; j += 1

        # Continually paste cards onto the template
        if j != 4:
            background.paste(img, (215 + i*(300+1448+30),147 + j*(250+913+26)))
            i += 1
        
        # If bottom of the page is met, save and load a new template
        elif j == 4:
            background.save(f"images/pages/page_{k}.png")
            background = blank_background.copy()

            # First image of the next page
            i = 0; j = 0; k += 1
            background.paste(img, (215 + i*(300+1448+30),147 + j*(250+913+26)))
            i += 1

        os.remove(f"images/cards/card_{tmp}.png")
    # Save image regardless of how many cards on last page
    background.save(f"images/pages/page_{k}.jpg", "JPEG")
#~~~~~~~~~~~~~~~~~~~~~~~~~~~~~~~~~~~~~~~~~~~~~~~~~~~~~~~~~~~~~~~~~~~~~~~~~~~~~~
def main():
    PullSpotifyData = False
    genCardPhotos(PullSpotifyData)
    genPaperPrints()
#~~~~~~~~~~~~~~~~~~~~~~~~~~~~~~~~~~~~~~~~~~~~~~~~~~~~~~~~~~~~~~~~~~~~~~~~~~~~~~
if __name__ == "__main__":
    main()

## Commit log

2022-04-12 Added GPIO button functionality
2022-04-22 Working prototype
2022-05-04 Working to make printable album art
2022-05-06 Readme updates and CAD files
    [BOTTOM_FRAME.stl, CARD_STACK_FRAME.stl, FRAME.stl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]
2022-05-20 Added more graphics to card prints
2022-05-20 Finishing artwork printouts
2023-06-24 Removing device_id
2023-06-24 Re-added device_id
